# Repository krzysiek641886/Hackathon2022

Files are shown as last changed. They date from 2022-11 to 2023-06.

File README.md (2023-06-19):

# Hackathon2022

This project a working repository that was used during a hackathon. The project consisted of a leveled plane for golf that could represent an unevenness of the ground while playing on a simulator.
- Arduino code for controlling electric motors connected to a leveled plane.
- Python script that calculates an angle based on Unity's representation of a surface in JSON
- Autodesk Inventor models of parts used for building the plane

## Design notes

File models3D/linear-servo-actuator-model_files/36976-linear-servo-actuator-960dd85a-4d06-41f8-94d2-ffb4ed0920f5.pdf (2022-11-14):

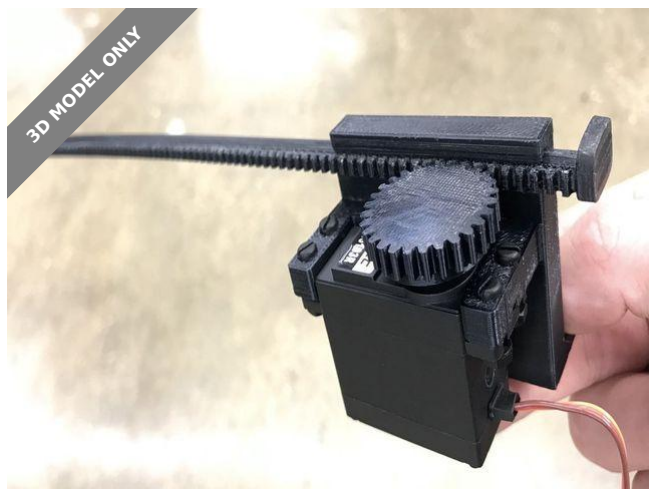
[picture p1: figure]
3D MODEL ONLY

# Summary

Linear actuator used for Adafruit's Xenomorph Halloween candy bucket

project.

Costumes & Accessories (https://www.printables.com/model?categoryId=76) | > | Other Costume Accessories (https://www.printables.com/model?categoryId=80)

Linear actuator used for Adafruit's Xenomorph Halloween candy bucket

project.

https://learn.adafruit.com/xenomorph-halloween-candy-bucket

Remixed from potentprintables original Linear Servo Actuators:

https://www.thingiverse.com/thing:3170748

# Print instructions Category: Electronics Summary

Linear actuator used for Adafruit's Xenomorph Halloween candy bucket

project.

https://learn.adafruit.com/xenomorph-halloween-candy-bucket

Remixed from potentprintables original Linear Servo Actuators:

https://www.thingiverse.com/thing:3170748

# Print Settings

## Printer Brand: MakerBot

Printer: MakerBot Replicator 2

## danowall (https://www.printables.com/social/10248/about)

# Linear Servo Actuator

### VIEW IN BROWSER (https://www.printables.com/model/36976-linear-servo-actuator)

updated 12. 4. 2022 | published 23. 7. 2020

# Model files

Rafts: Doesn't Matter

## Supports: Yes

## Resolution: 0.20mm

## Infill: 40%

## Filament: N/A PLA Black

Find source .stl files on Thingiverse.com (https://www.thingiverse.com/thing:3880339)

# License

This work is licensed under a

Creative Commons (4.0 International License)

Attribution (http://creativecommons.org/licenses/by/4.0/)

### ✖ | Sharing without ATTRIBUTION

✔ | Remix Culture allowed
✔ | Commercial Use
✔ | Free Cultural Works
✔ | Meets Open Definition

## pinion_gear_large_version.stl

## pusher_220mm.stl

## motor_bracket_revision.stl

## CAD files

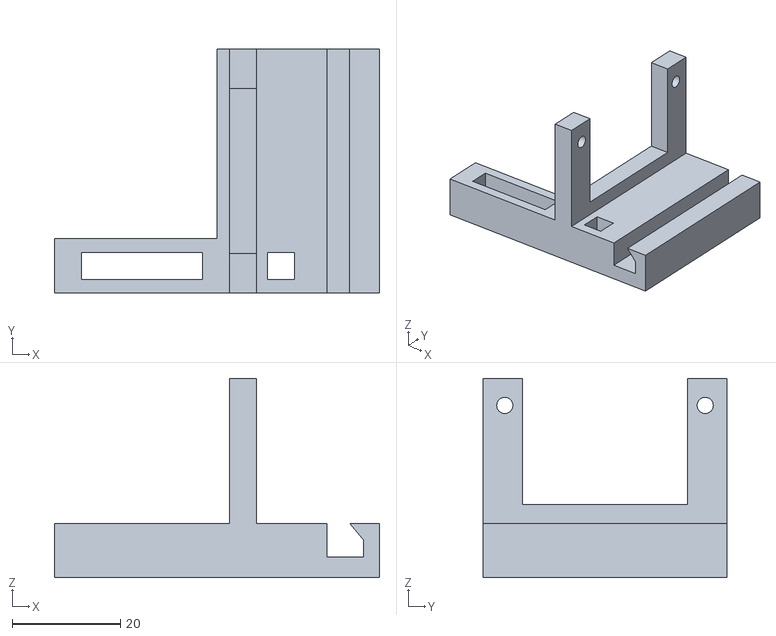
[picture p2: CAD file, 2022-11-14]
models3D/linear-servo-actuator-model_files/Frame.stl
60.0 x 45.0 x 36.8

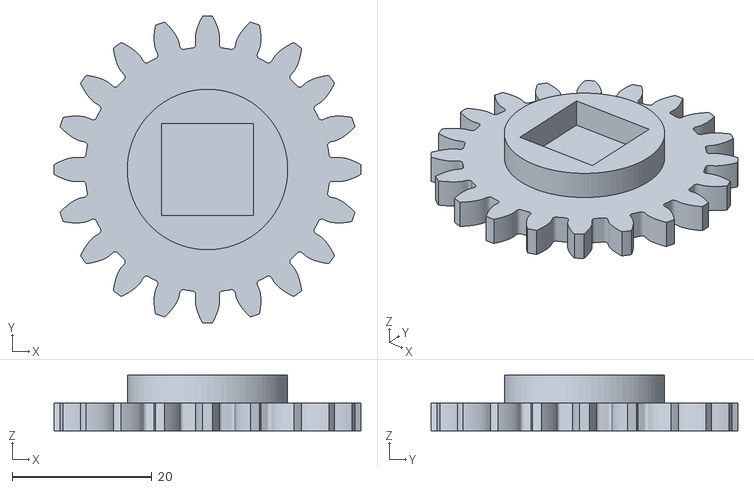
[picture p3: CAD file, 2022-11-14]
models3D/linear-servo-actuator-model_files/Gear v3.stl
44.0 x 44.0 x 8.00

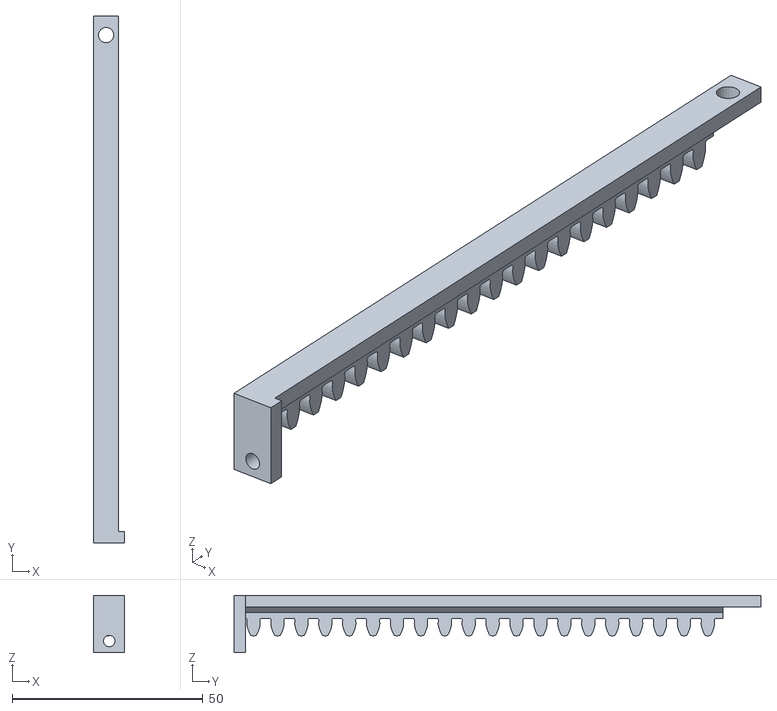
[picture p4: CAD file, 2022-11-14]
models3D/linear-servo-actuator-model_files/Pusher.stl
8.00 x 138.0 x 15.0

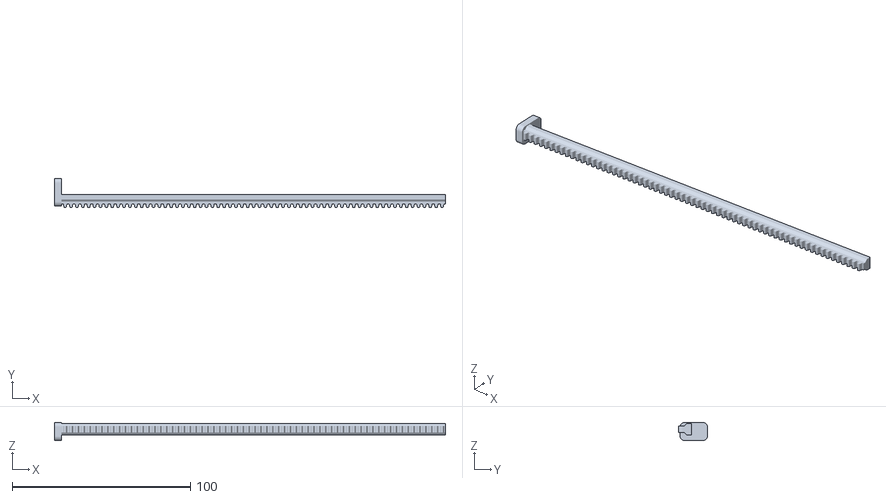
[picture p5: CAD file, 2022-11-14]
models3D/linear-servo-actuator-model_files/pusher_220mm.stl
219.2 x 16.3 x 10.2

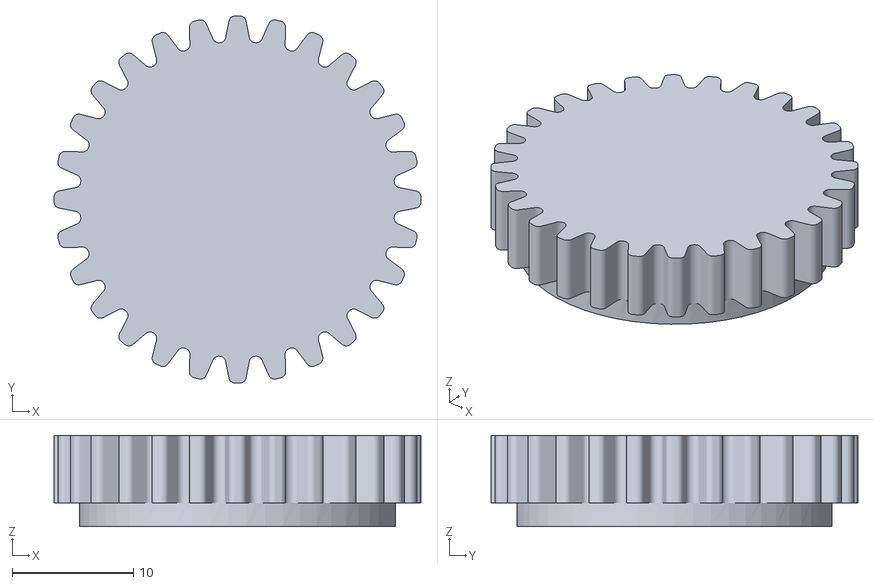
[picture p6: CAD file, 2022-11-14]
models3D/linear-servo-actuator-model_files/pinion_gear_large_version.stl
30.2 x 30.2 x 7.51

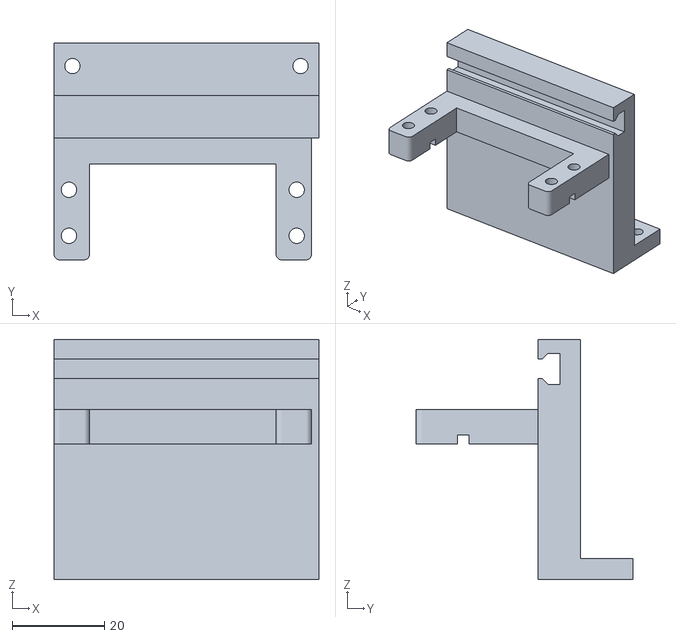
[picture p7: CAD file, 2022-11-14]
models3D/linear-servo-actuator-model_files/motor_bracket_revision.stl
57.6 x 47.1 x 52.2

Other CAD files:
models3D/linear-servo-actuator-model_files/FrameV1.f3d

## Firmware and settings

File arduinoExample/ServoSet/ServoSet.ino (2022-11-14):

/* Sweep
  by BARRAGAN <http://barraganstudio.com>
  This example code is in the public domain.

  modified 28 May 2015
  by Michael C. Miller
  modified 8 Nov 2013
  by Scott Fitzgerald

  http://arduino.cc/en/Tutorial/Sweep
*/

#include <math.h>
#include <Servo.h>

Servo servo0;  // create servo object to control a servo
Servo servo1;  // create servo object to control a servo
Servo servo2;
Servo servo3;
// twelve servo objects can be created on most boards


void setup() {
  // initialize serial:
  Serial.begin(115200);
  Serial.println("hello world");


  servo0.attach(15, 500, 2500);  // attaches the servo on GIO15 to the servo object
  servo1.attach(14, 500, 2500);  // attaches the servo on GIO14 to the servo object
  servo2.attach(13, 500, 2500);  // attaches the servo on GIO13 to the servo object
  servo3.attach(12, 500, 2500);  // attaches the servo on GIO12 to the servo object


  Serial.println("PLease input two angles, seperatred with ','.");
}


int incomingByte = 0;
char serialBuffer[64];
int bufferIndex = 0;
int strLength = 0;
int seperatorIndex[] = {0,0};

int pitch = 0;
int roll = 0;

int servoAngle[] = {0,0};
int servoIndex = 0;

float temp = 0;

//Flags
bool recievedString = false;
bool updateServos = false;

void loop() {
  int pos;
  
  
  
  
  while (Serial.available() > 0) {
    incomingByte = Serial.read();
    Serial.print(char(incomingByte));
    serialBuffer[bufferIndex++] = incomingByte;

    if (incomingByte == '\r')
    {
      Serial.println();
      serialBuffer[bufferIndex] = 0;
      strLength = bufferIndex;
      //Serial.println("got \\r");
      bufferIndex = 0;

      // Find seperarting charecter
      for (int i = 0; i <= strLength; i++)
      {
        seperatorIndex[1] = i+1;
        if (serialBuffer[i] == ',')
        {
          break;
        }
        
      }
      // abort if no seperator is found.
      if (seperatorIndex[1] >= strLength )
      {
        Serial.println("No ',' found, please input 2 angles.");
        break;
      }
      // Serial.print("Seperator index: ");
      // Serial.println(seperatorIndex[1] );
      // Serial.println(serialBuffer+seperatorIndex[1] );


    
      
      // get pitch and roll from input.
      pitch = atoi(serialBuffer+seperatorIndex[0]);
      roll = atoi(serialBuffer+seperatorIndex[1]);
      Serial.print("pitch angle: "); Serial.print(pitch); Serial.print("  ");
      Serial.print("roll angle: "); Serial.print(roll);
      Serial.println("");


      // Serial.print("tangent of pitch using (double) rad : ");
      // Serial.println ( tan (double(pitch)/(180.0/3.1415)) ); // returns tangent of x
      // Serial.print("tangent of pitch using deg : ");
      // Serial.println ( tan (pitch) ); // returns tangent of x
      // Serial.print("tangent of pitch using (double) deg : ");
      // Serial.println ( tan (double(pitch)) ); // returns tangent of x
      // Serial.print("130.0/(40.0/180.0) =  ");
      // temp = 130.0/(40.0/180.0);
      // Serial.println ( temp );



      // tan(pitch)*130mm  /  ( 40mm/180deg ) = degServo
      // servoAngle[0] = (tan(pitch)*130.0)/(40.0/180.0);
      // servoAngle[1] = (tan(roll)*130.0)/(40.0/180.0);
      servoAngle[0] = int(  tan(double(pitch)/(180.0/3.1415)) * ((585/2)*1.15) );
      servoAngle[1] = int(  tan(double(roll)/(180.0/3.1415)) * ((585/2)*1.15) );
      
      Serial.print("pitchServo: "); Serial.print(servoAngle[0]); Serial.print("  ");
      Serial.print("rollServo: "); Serial.print(servoAngle[1]);
      Serial.println("");
      
      updateServos = true;
      // servoAngle[0] = 0;
      // servoAngle[1] = 0;
    }
    
  }

  if (updateServos)
  {
    updateServos = false;

    for (int i = 0; i < 2; i++)
    {
      if (servoAngle[i] > 90)
      {
        servoAngle[i] = 90;
      }
      if (servoAngle[i] < -90)
      {
        servoAngle[i] = -90;
      }
    }
    

    Serial.print("Moving to angle: ");
    Serial.println(servoAngle[0]+90);
    servo0.write(servoAngle[0]+90);              // tell servo to go to position in variable 'pos'
    
    Serial.print("Moving to angle: ");
    Serial.println(90-servoAngle[0]);
    servo1.write(90-servoAngle[0]);              // tell servo to go to position in variable 'pos'


    updateServos = false;
    Serial.print("Moving to angle: ");
    Serial.println(servoAngle[1]+90);
    servo2.write(servoAngle[1]+90);              // tell servo to go to position in variable 'pos'
    
    Serial.print("Moving to angle: ");
    Serial.println(90-servoAngle[1]);
    servo3.write(90-servoAngle[1]);              // tell servo to go to position in variable 'pos'

    Serial.println();
  }
  

  
}

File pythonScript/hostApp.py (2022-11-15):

#!/usr/bin/python
import numpy
import sys
import json
import matplotlib.pyplot as plt
from mpl_toolkits.mplot3d import Axes3D
import serial
import time

STEP = 5.0
MIN = -50
MAX = 50


def getXYZ(data):
    x = []
    y = []
    z = []
    for point in data:
        x.append(point["x"])
        y.append(point["y"])
        z.append(point["z"])
    return [x, y, z]


def print_plot(x, y, z, pos_x, pos_y, pos_z):
    fig = plt.figure()
    ax = fig.add_subplot(111, projection='3d')
    ax.scatter(x, y, z, zdir='z', c='green')
    ax.scatter(pos_x, pos_y, pos_z, zdir='z', c='red', s=500)
    
    plt.show()



def find_index(pos_x, pos_y, x_arr, y_arr):
    i = x_arr.index(pos_x)
    for i in range(i, len(x_arr)):
        if y_arr[i] == pos_y:
            return i
    sys.exit(-1)


def find_neighbours(x_arr, y_arr, z_arr, matching_index):
    row_size = int(round((MAX - MIN) / STEP))
    neighbours = {
        "left_neighbour": {
        "x": x_arr[matching_index - row_size],
        "y": y_arr[matching_index - row_size],
        "z": z_arr[matching_index - row_size]
    },
        "right_neighbour": {
        "x": x_arr[matching_index + row_size],
        "y": y_arr[matching_index + row_size],
        "z": z_arr[matching_index + row_size]
    },
        "front_neighbour": {
        "x": x_arr[matching_index + 1],
        "y": y_arr[matching_index + 1],
        "z": z_arr[matching_index + 1]
    },
        "back_neighbour": {
        "x": x_arr[matching_index - 1],
        "y": y_arr[matching_index - 1],
        "z": z_arr[matching_index - 1]
    }}
    return neighbours

def get_angles(nabo):
    ln = nabo["left_neighbour"]
    rn = nabo["right_neighbour"]
    fn = nabo["front_neighbour"]
    bn = nabo["back_neighbour"]

    pitch = numpy.rad2deg(numpy.arctan( (fn["z"] - bn["z"]) / (STEP * 2)) )
    roll = numpy.rad2deg(numpy.arctan( (ln["z"] - rn["z"]) / (STEP * 2)))
    return [pitch, roll]

def mainFunctionality(pos_x, pos_y, com_port, x, y, z):
    pos_x = round(float(pos_x) * 2) / 2
    pos_y = round(float(pos_y) * 2) / 2
    matching_index = find_index(pos_x, pos_y, x, y)
    pos_z = z[matching_index]
    
    neighbours = find_neighbours(x, y, z, matching_index)
    angles = get_angles(neighbours)

    
    ser = serial.Serial()
    ser.baudrate = 115200
    ser.port = com_port
    ser.open()

    # Send character ' to start the program
    print('{},{}'.format(int(angles[0]),int(angles[1])))
    ser.write(bytearray('{},{}\r'.format(angles[0],angles[1]),'ascii'))
    print_plot(x, y, z, pos_x, pos_y, pos_z)

def disco(comport):
    ser = serial.Serial()
    ser.baudrate = 115200
    ser.port = comport
    ser.open()
    angles = [0,0]
    
    for i in range(2):
        angles[0] = 10
        angles[1] = 5
        print('{},{}'.format(int(angles[0]),int(angles[1])))
        ser.write(bytearray('{},{}\r'.format(angles[0],angles[1]),'ascii'))
        time.sleep(0.5)
        
        angles[0] = 5
        angles[1] = 10
        print('{},{}'.format(int(angles[0]),int(angles[1])))
        ser.write(bytearray('{},{}\r'.format(angles[0],angles[1]),'ascii'))
        time.sleep(0.5)
        
        angles[0] = 0
        angles[1] = 5
        print('{},{}'.format(int(angles[0]),int(angles[1])))
        ser.write(bytearray('{},{}\r'.format(angles[0],angles[1]),'ascii'))
        time.sleep(0.5)
        
        angles[0] = -5
        angles[1] = 10
        print('{},{}'.format(int(angles[0]),int(angles[1])))
        ser.write(bytearray('{},{}\r'.format(angles[0],angles[1]),'ascii'))
        time.sleep(0.5)
        
        angles[0] = -10
        angles[1] = 5
        print('{},{}'.format(int(angles[0]),int(angles[1])))
        ser.write(bytearray('{},{}\r'.format(angles[0],angles[1]),'ascii'))
        time.sleep(0.5)
        
        angles[0] = -5
        angles[1] = 0
        print('{},{}'.format(int(angles[0]),int(angles[1])))
        ser.write(bytearray('{},{}\r'.format(angles[0],angles[1]),'ascii'))
        
        angles[0] = 0
        angles[1] = 0
        print('{},{}'.format(int(angles[0]),int(angles[1])))
        ser.write(bytearray('{},{}\r'.format(angles[0],angles[1]),'ascii'))
        
        angles[1] = 5
        angles[0] = 0
        print('{},{}'.format(int(angles[0]),int(angles[1])))
        ser.write(bytearray('{},{}\r'.format(angles[0],angles[1]),'ascii'))
        
        angles[1] = 10
        angles[0] = 5
        print('{},{}'.format(int(angles[0]),int(angles[1])))
        ser.write(bytearray('{},{}\r'.format(angles[0],angles[1]),'ascii'))
        time.sleep(0.5)
        
        angles[1] = 5
        angles[0] = 10
        print('{},{}'.format(int(angles[0]),int(angles[1])))
        ser.write(bytearray('{},{}\r'.format(angles[0],angles[1]),'ascii'))
        time.sleep(0.5)
        
        angles[1] = 0
        angles[0] = 5
        print('{},{}'.format(int(angles[0]),int(angles[1])))
        ser.write(bytearray('{},{}\r'.format(angles[0],angles[1]),'ascii'))
        time.sleep(0.5)
        
        angles[1] = -5
        angles[0] = 10
        print('{},{}'.format(int(angles[0]),int(angles[1])))
        ser.write(bytearray('{},{}\r'.format(angles[0],angles[1]),'ascii'))
        time.sleep(0.5)
        
        angles[1] = -10
        angles[0] = 5
        print('{},{}'.format(int(angles[0]),int(angles[1])))
        ser.write(bytearray('{},{}\r'.format(angles[0],angles[1]),'ascii'))
        time.sleep(0.5)
        
        angles[1] = -5
        angles[0] = 0
        print('{},{}'.format(int(angles[0]),int(angles[1])))
        ser.write(bytearray('{},{}\r'.format(angles[0],angles[1]),'ascii'))
        time.sleep(0.5)
        
        angles[1] = 0
        angles[0] = 0
        print('{},{}'.format(int(angles[0]),int(angles[1])))
        ser.write(bytearray('{},{}\r'.format(angles[0],angles[1]),'ascii'))
        
    sys.exit(0)


def main(argv):
    if ("help" in argv[0] or len(argv) != 4):
        print("Call program with following order:")
        print("python hostApp.py <map_grid_file> <point_x_coordinate> <point_y_coordinate> <com-port>")
        sys.exit(0)
    elif (argv[1] == '1'  and argv[2] == '-1'):
        print("DISCO!")
        disco(argv[3])
    else:
        f = open(argv[0])
        data = json.load(f)
        [x_arr, y_arr, z_arr] = getXYZ(data)
        pos_x = argv[1]
        pos_y = argv[2]
        com_port = argv[3]

        while True:
            mainFunctionality(pos_x, pos_y, com_port, x_arr, y_arr, z_arr)
            inp = input('Some more coordinates? Write exit to stop\n')
            args = inp.split(",")
            if "exit" in inp or len(args) != 2:
                break
            print(args)
            pos_x = args[0]
            pos_y = args[1]

if __name__ == "__main__":
    main(sys.argv[1:])

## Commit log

2022-11-14 Added models
    [linear_actuator.stl]
2022-11-14 Added example code for servo.
2022-11-14 Working on models
    [FrameV1.f3d, linear_actuator.stl, motor_bracket_revision.stl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]
2022-11-14 Added servo with uart input.
2022-11-14 Changed servos to operate in diff mode.
2022-11-14 added 2 more servos
2022-11-14 working models added
    [Frame.stl, Gear v3.stl, Pusher.stl]
2022-11-14 Printing plot
2022-11-14 Added calculation from green angle to motor andgles.
